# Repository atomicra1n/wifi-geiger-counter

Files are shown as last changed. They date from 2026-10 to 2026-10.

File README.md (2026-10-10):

# Wi-Fi Geiger Counter

a DIY Geiger counter PCB which can detect ionizing radiation and log readings over Wi-Fi,. Built with an ESP32, and a HV multiplier circuit that steps up 3.7V to 400V for the GM tube.



## Features

- M4011/SBM-20 Geiger tube with pulse detection
- Custom HV circuit (around 400V) with a single LiPo cell
- Wi-Fi data logging
- USB-C charging
- ESD and overvoltage protection

Build for [Hack Club Half Life](https://halflife.hackclub.com/) 
Week 1 (PCBs).

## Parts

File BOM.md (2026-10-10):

# Wi-Fi Geiger Counter – bill of materials

<!-- Generated by Half Life from project cmuvjsap500od01pymkzg6tec. Edits here are overwritten on the next sync. -->
<!-- Generated: 2026-10-10T20:25:37.913Z -->

> [!NOTE]
> This parts list is mirrored from [Half Life](https://halflife.hackclub.com). Editing it here will not change the platform's copy, and the next sync overwrites this file.

| Week | Tier | Parts funding |
| --- | --- | --- |
| Week 1 | Tier 2 | $65.00 |

| Part | What it's for | Qty | Unit | Total | Vendor |
| --- | --- | --- | --- | --- | --- |
| [PCB Manufacturing](https://jlcpcb.com) | The entire PCB itself | 1 | $4.00 | $4.00 | [JLCPCB](https://jlcpcb.com) |
| [EPS32-C3-MINI](https://www.lcsc.com/product-detail/C2838502.html) | The PCB controller | 1 | $3.06 | $3.06 | [LCSC](https://www.lcsc.com/product-detail/C2838502.html) |
| [TP4056-42-ESOP8](https://www.lcsc.com/product-detail/C16581.html) | Charges the LiPo battery from USB | 5 | $0.19 | $0.95 | [LCSC](https://www.lcsc.com/product-detail/C16581.html) |
| [AP2112K-3.3TRG1](https://www.lcsc.com/product-detail/C51118.html) | Regulates battery voltage down to 3.3V | 5 | $0.18 | $0.90 | [LCSC](https://www.lcsc.com/product-detail/C51118.html) |
| [USBLC6-2SC6](https://www.lcsc.com/product-detail/C7519.html) | Protects USB data lines from static | 5 | $0.18 | $0.90 | [LCSC](https://www.lcsc.com/product-detail/C7519.html) |
| [MMBTA42](https://www.lcsc.com/product-detail/C94389.html) | Switches the inductor for HV boost converter | 10 | $0.05 | $0.50 | [LCSC](https://www.lcsc.com/product-detail/C94389.html) |
| [MMBT3904](https://www.lcsc.com/product-detail/C242260.html) | Pulse detection + buzzer driver | 20 | $0.04 | $0.80 | [LCSC](https://www.lcsc.com/product-detail/C242260.html) |
| [US1M](https://www.lcsc.com/product-detail/C81191.html) | HV multiplier rectifier diodes | 3 | $0.05 | $0.15 | [LCSC](https://www.lcsc.com/product-detail/C81191.html) |
| [1N4148W](https://www.lcsc.com/product-detail/C917030.html) | Buzzer flyback diode | 50 | $0.01 | $0.50 | [LCSC](https://www.lcsc.com/product-detail/C917030.html) |
| [SMF5.0A](https://www.lcsc.com/product-detail/C151296.html) | USB TVS protection | 5 | $0.13 | $0.65 | [LCSC](https://www.lcsc.com/product-detail/C151296.html) |
| [MM3Z3V3](https://www.lcsc.com/product-detail/C52056.html) | 3.3V zener clamp on pulse input | 50 | $0.02 | $1.00 | [LCSC](https://www.lcsc.com/product-detail/C52056.html) |
| [Red LED 0805](https://www.lcsc.com/product-detail/C84256.html) | Charge + status indicators | 50 | $0.02 | $1.00 | [LCSC](https://www.lcsc.com/product-detail/C84256.html) |
| [Yellow LED 0805](https://www.lcsc.com/product-detail/C84261.html) | Charge complete indicator | 20 | $0.02 | $0.40 | [LCSC](https://www.lcsc.com/product-detail/C84261.html) |
| [MLT-8530](https://www.lcsc.com/product-detail/C94599.html) | Click and alarm buzzer | 5 | $0.21 | $1.05 | [LCSC](https://www.lcsc.com/product-detail/C94599.html) |
| [FNR6045S103KT](https://www.lcsc.com/product-detail/C168108.html) | HV boost inductor | 5 | $0.25 | $1.25 | [LCSC](https://www.lcsc.com/product-detail/C168108.html) |
| [TYPE-C-31-M-12](https://www.lcsc.com/product-detail/C165948.html) | USB-C charging port | 5 | $0.18 | $0.90 | [LCSC](https://www.lcsc.com/product-detail/C165948.html) |
| [S2B-PH-K-S-GW](https://www.lcsc.com/product-detail/C157932.html) | Battery connector | 5 | $0.17 | $0.85 | [LCSC](https://www.lcsc.com/product-detail/C157932.html) |
| [1k 0805](https://www.lcsc.com/product-detail/C17513.html) | LED/transistor current limiting, pulse protection | 100 | $0.01 | $1.00 | [LCSC](https://www.lcsc.com/product-detail/C17513.html) |
| [10k 0805](https://www.lcsc.com/product-detail/C17414.html) | Pullups, pulldowns, base resistors | 100 | $0.01 | $1.00 | [LCSC](https://www.lcsc.com/product-detail/C17414.html) |
| [5.1k 0805](https://www.lcsc.com/product-detail/C27834.html) | USB-C CC pulldowns | 100 | $0.01 | $1.00 | [LCSC](https://www.lcsc.com/product-detail/C27834.html) |
| [2.2k 0805](https://www.lcsc.com/product-detail/C17520.html) | TP4056 charge current setting | 100 | $0.01 | $1.00 | [LCSC](https://www.lcsc.com/product-detail/C17520.html) |
| [220k 0805](https://www.lcsc.com/product-detail/C17556.html) | HV feedback divider bottom | 100 | $0.01 | $1.00 | [LCSC](https://www.lcsc.com/product-detail/C17556.html) |
| [100k 0805](https://www.lcsc.com/product-detail/C17407.html) | Tube cathode load resistor | 100 | $0.01 | $1.00 | [LCSC](https://www.lcsc.com/product-detail/C17407.html) |
| [4.7M 1206 500V](https://www.lcsc.com/product-detail/C510138.html) | Tube anode current limiter | 10 | $0.01 | $0.10 | [LCSC](https://www.lcsc.com/product-detail/C510138.html) |
| [10M 1206](https://www.lcsc.com/product-detail/C2933576.html) | HV feedback divider chain | 100 | $0.01 | $1.00 | [LCSC](https://www.lcsc.com/product-detail/C2933576.html) |
| [10µF 0805](https://www.lcsc.com/product-detail/C15850.html) | Power rail decoupling | 20 | $0.07 | $1.40 | [LCSC](https://www.lcsc.com/product-detail/C15850.html) |
| [1µF 0805](https://www.lcsc.com/product-detail/C28323.html) | LDO input/output filtering | 10 | $0.04 | $0.40 | [LCSC](https://www.lcsc.com/product-detail/C28323.html) |
| [100nF 0805](https://www.lcsc.com/product-detail/C49678.html) | High-frequency decoupling | 20 | $0.02 | $0.40 | [LCSC](https://www.lcsc.com/product-detail/C49678.html) |
| [10nF 1kV 1206](https://www.lcsc.com/product-detail/C107192.html) | HV multiplier stage caps | 20 | $0.03 | $0.60 | [LCSC](https://www.lcsc.com/product-detail/C107192.html) |
| [Tact switch](https://www.lcsc.com/product-detail/C318884.html) | Reset + boot buttons | 20 | $0.02 | $0.40 | [LCSC](https://www.lcsc.com/product-detail/C318884.html) |
| [GM Tube - M4011](https://github.com/SensorsIot/Geiger-Counter-RadiationD-v1.1-CAJOE-/blob/master/M4011%20Geiger%20Tube%20Specification.pdf) | Detecting radioactive impulses | 1 | $0.01 | $0.01 | [Myself - Salvaged from FNIRSI GC-01](https://github.com/SensorsIot/Geiger-Counter-RadiationD-v1.1-CAJOE-/blob/master/M4011%20Geiger%20Tube%20Specification.pdf) |
| [3.7V LiPo battery](https://tipa.eu/en-en/products/rechargeable-battery-lipo-3-7v4200mah-105565-hadex) | Power delivery | 1 | $0.01 | $0.01 | [Myself - Salvaged from FNIRSI GC-01](https://tipa.eu/en-en/products/rechargeable-battery-lipo-3-7v4200mah-105565-hadex) |
| [2.54-1*3P](https://www.lcsc.com/product-detail/C49257.html) | GM Tube pin header | 20 | $0.03 | $0.60 | [LCSC](https://www.lcsc.com/product-detail/C49257.html) |
| **Parts subtotal** | — | — | — | **$29.78** | — |
| **Tax & shipping** | — | — | — | **$25.00** | — |
| **Total** | — | — | — | **$54.78** | — |

$10.22 left of the tier's funding.

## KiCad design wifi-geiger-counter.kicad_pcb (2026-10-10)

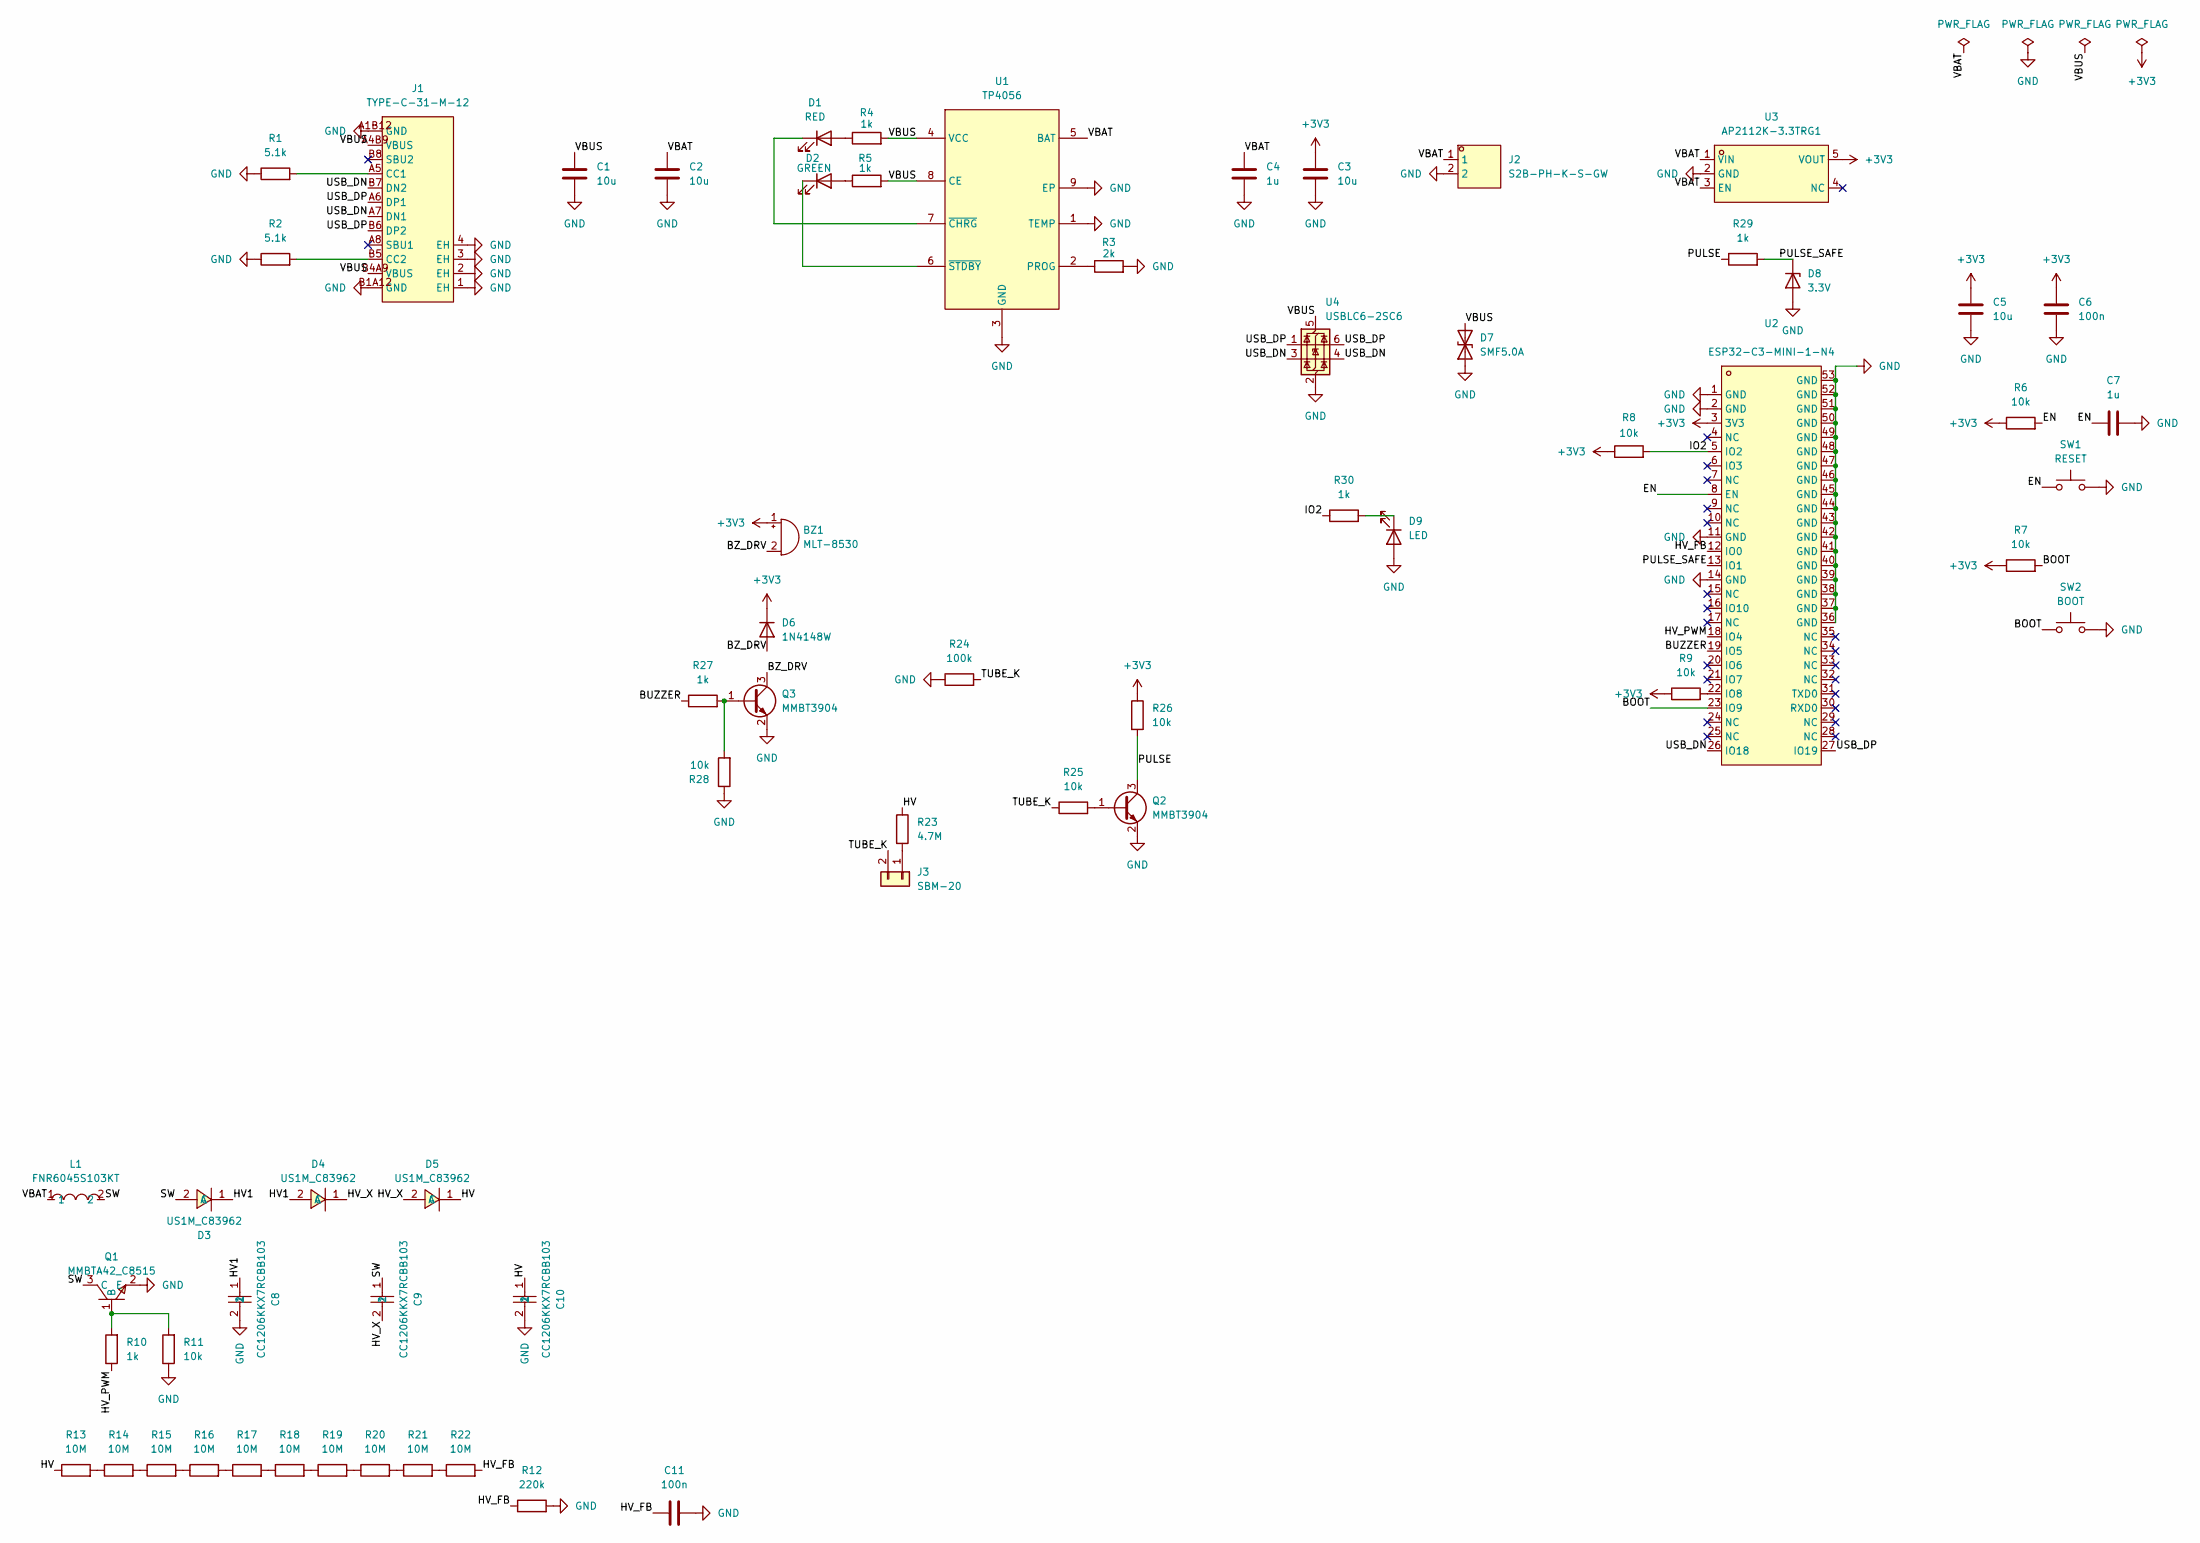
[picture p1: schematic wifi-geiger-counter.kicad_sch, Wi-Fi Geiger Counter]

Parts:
BZ1: MLT-8530; Buzzer_Murata_PKMCS0909E
C1, C2, C3, C5: 10u; C_0805_2012Metric
C4, C7: 1u; C_0805_2012Metric
C6, C11: 100n; C_0805_2012Metric
C8, C9, C10: CC1206KKX7RCBB103; C1206; MPN CC1206KKX7RCBB103; LCSC Part C107192
D1: RED; LED_0805_2012Metric
D2: GREEN; LED_0805_2012Metric
D3, D4, D5: US1M_C83962; SMA_L4.3-W2.6-LS5.2-RD; MPN US1M; LCSC Part C83962
D6: 1N4148W; D_SOD-123
D7: SMF5.0A; D_SOD-123F
D8: 3.3V; D_SOD-323
D9: LED; LED_0805_2012Metric
J1: TYPE-C-31-M-12; USB-C_SMD-TYPE-C-31-M-12_1; MPN TYPE-C-31-M-12; LCSC Part C165948
J2: S2B-PH-K-S-GW; CONN-TH_S2B-PH-K-S-GW; MPN S2B-PH-K-S-GW; LCSC Part C157932
J3: SBM-20; PinHeader_1x02_P2.54mm_Vertical
L1: FNR6045S103KT; IND-SMD_L6.0-W6.0_FNR60XXS; MPN FNR6045S103KT; LCSC Part C168108
Q1: MMBTA42_C8515; SOT-23-3_L2.9-W1.3-P1.90-LS2.4-BR; MPN MMBTA42(RANGE:100-200); LCSC Part C8515
Q2, Q3: MMBT3904; SOT-23
R1, R2: 5.1k; R_0805_2012Metric
R3: 2k; R_0805_2012Metric
R4, R5, R10, R27, R29, R30: 1k; R_0805_2012Metric
R6, R7, R8, R9, R11, R25, R26, R28: 10k; R_0805_2012Metric
R12: 220k; R_0805_2012Metric
R13, R14, R15, R16, R17, R18, R19, R20, R21, R22: 10M; R_1206_3216Metric
R23: 4.7M; R_1206_3216Metric
R24: 100k; R_0805_2012Metric
SW1: RESET; SW_SPST_CK_KMS2xxGP
SW2: BOOT; SW_SPST_CK_KMS2xxGP
U1: TP4056; ESOP-8_L4.9-W3.9-P1.27-LS6.0-BL-EP; MPN TP4056-42-ESOP8; LCSC Part C16581
U2: ESP32-C3-MINI-1-N4; WIFIM-SMD_ESP32-C3-MINI-1; MPN ESP32-C3-MINI-1-N4; LCSC Part C2838502
U3: AP2112K-3.3TRG1; SOT-25-5_L2.9-W1.6-P0.95-LS2.8-BL; MPN AP2112K-3.3TRG1; LCSC Part C51118
U4: USBLC6-2SC6; SOT-23-6

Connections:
+3V3: BZ1.1 (+), C3.1, C5.1, C6.1, D6.1 (K), R6.1, R7.1, R8.1, R9.1, R26.1, U2.3 (3V3), U3.5 (VOUT)
/BOOT: R7.2, SW2.1, U2.23 (IO9)
/BUZZER: R27.1, U2.19 (IO5)
/BZ_DRV: BZ1.2 (-), D6.2 (A), Q3.3 (C)
/EN: C7.2, R6.2, SW1.1, U2.8 (EN)
/HV: C10.1, D5.1 (C), R13.1, R23.1
/HV1: C8.1, D3.1 (C), D4.2 (A)
/HV_FB: C11.1, R12.1, R22.2, U2.12 (IO0)
/HV_PWM: R10.1, U2.18 (IO4)
/HV_X: C9.2, D4.1 (C), D5.2 (A)
/IO2: R8.2, R30.1, U2.5 (IO2)
/PULSE: Q2.3 (C), R26.2, R29.1
/PULSE_SAFE: D8.1 (K), R29.2, U2.13 (IO1)
/SW: C9.1, D3.2 (A), L1.2, Q1.3 (C)
/TUBE_K: J3.2, R24.2, R25.1
/USB_DN: J1.A7 (DN1), J1.B7 (DN2), U2.26 (IO18), U4.3 (I/O2), U4.4 (I/O2)
/USB_DP: J1.A6 (DP1), J1.B6 (DP2), U2.27 (IO19), U4.1 (I/O1), U4.6 (I/O1)
/VBAT: C2.1, C4.1, J2.1, L1.1, U1.5 (BAT), U3.1 (VIN), U3.3 (EN)
/VBUS: C1.2, D7.2 (A2), J1.A4B9 (VBUS), J1.B4A9 (VBUS), R4.2, R5.2, U1.4 (VCC), U1.8 (CE), U4.5 (VBUS)
GND: C1.1, C2.2, C3.2, C4.2, C5.2, C6.2, C7.1, C8.2, C10.2, C11.2, D7.1 (A1), D8.2 (A), D9.2 (A), J1.1 (EH), J1.2 (EH), J1.3 (EH), J1.4 (EH), J1.A1B12 (GND), J1.B1A12 (GND), J2.2, Q1.2 (E), Q2.2 (E), Q3.2 (E), R1.1, R2.1, R3.2, R11.1, R12.2, R24.1, R28.1, SW1.2, SW2.2, U1.1 (TEMP), U1.3 (GND), U1.9 (EP), U2.1 (GND), U2.2 (GND), U2.11 (GND), U2.14 (GND), U2.36 (GND), U2.37 (GND), U2.38 (GND), U2.39 (GND), U2.40 (GND), U2.41 (GND), U2.42 (GND), U2.43 (GND), U2.44 (GND), U2.45 (GND), U2.46 (GND), U2.47 (GND), U2.48 (GND), U2.49 (GND), U2.50 (GND), U2.51 (GND), U2.52 (GND), U2.53 (GND), U3.2 (GND), U4.2 (GND)
unnamed: D1.2 (A), R4.1
unnamed: D1.1 (K), U1.7 (~CHRG)
unnamed: D2.2 (A), R5.1
unnamed: D2.1 (K), U1.6 (~STDBY)
unnamed: D9.1 (K), R30.2
unnamed: J1.A5 (CC1), R1.2
unnamed: J1.B5 (CC2), R2.2
unnamed: J3.1, R23.2
unnamed: Q1.1 (B), R10.2, R11.2
unnamed: Q2.1 (B), R25.2
unnamed: Q3.1 (B), R27.2, R28.2
unnamed: R13.2, R14.1
unnamed: R14.2, R15.1
unnamed: R15.2, R16.1
unnamed: R16.2, R17.1
unnamed: R17.2, R18.1
unnamed: R18.2, R19.1
unnamed: R19.2, R20.1
unnamed: R20.2, R21.1
unnamed: R21.2, R22.1
unnamed: R3.1, U1.2 (PROG)
unnamed: R9.2, U2.22 (IO8)

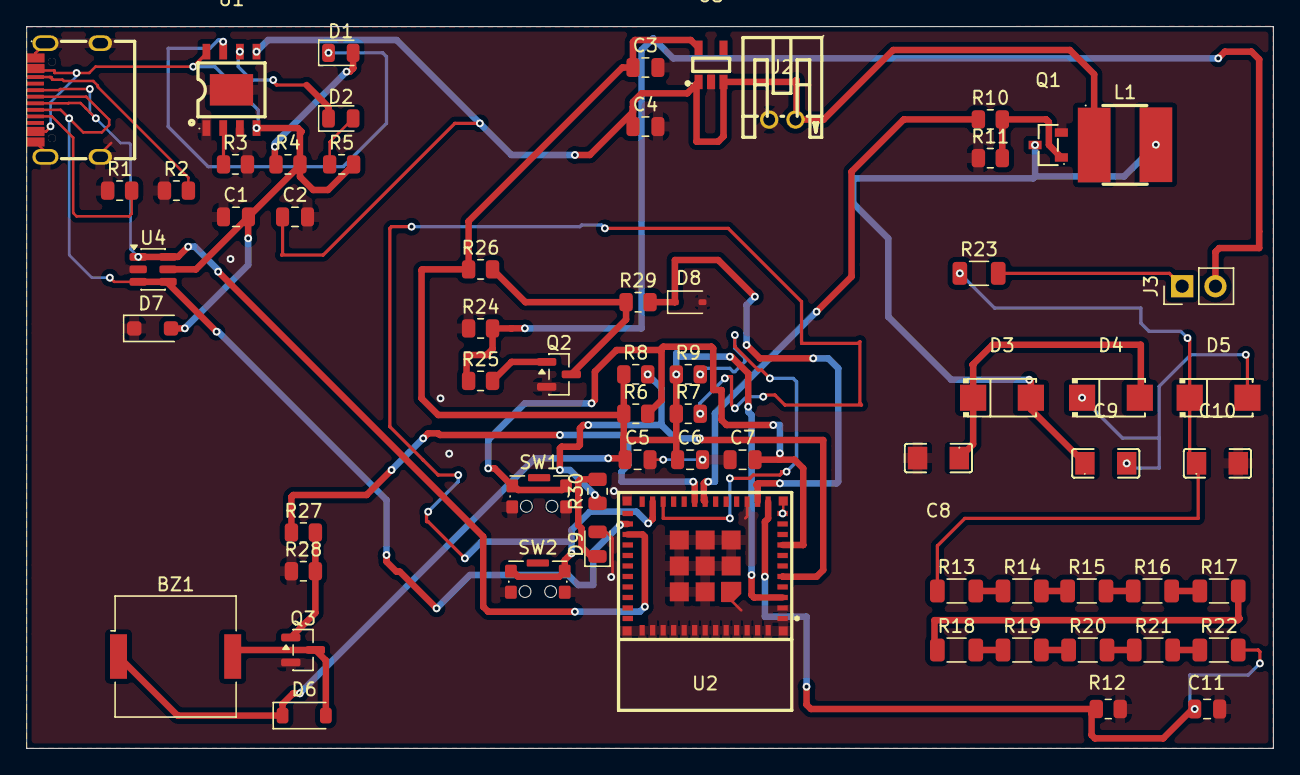
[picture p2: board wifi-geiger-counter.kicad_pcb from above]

Board: 2 copper layers, 95.0 x 55.0 mm, 64 parts (0 on the bottom side), 42 nets.

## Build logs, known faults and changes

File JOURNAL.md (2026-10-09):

# Wi-Fi Geiger Counter – devlog

<!-- Generated by Half Life from project cmuvjsap500od01pymkzg6tec. Edits here are overwritten on the next sync. -->
<!-- Generated: 2026-10-08T21:40:39.430Z -->

> [!NOTE]
> This devlog is mirrored from [Half Life](https://halflife.hackclub.com). Editing it here will not change the platform's copy, and the next sync overwrites this file.

> A Geiger counter that logs current radiation levels over Wi-Fi. Uses a SBM-20 Geiger tube, ESP32-C3 and a self-designed high voltage supply. Powered over USB-C + a battery.

| Week | Tier | Hours logged | Entries |
| --- | --- | --- | --- |
| Week 1 | Tier 2 | 17h | 4 |

## Contents

1. [2026-10-06 – # Oct 5: Planning and first work in KiCad](#2026-10-06-oct-5-planning-and-first-work-in-kicad)
2. [2026-10-06 – # Oct 6: Footprint assignment](#2026-10-06-oct-6-footprint-assignment)
3. [2026-10-07 – # Oct 7: PCB layout: placement and first routing](#2026-10-07-oct-7-pcb-layout-placement-and-first-routing)
4. [2026-10-08 – # Oct 8: Routing the board](#2026-10-08-oct-8-routing-the-board)

## Design

### 2026-10-06 – # Oct 5: Planning and first work in KiCad

**9h**

# Oct 5: Planning and first work in KiCad
After coming up with my project concept, I first decided to make a list of the parts I would work with and features I would want. I already have a FNIRSI GC-01 Geiger Counter, so I have a good reference of readings and problems with it. The readings often jump a lot at low radiation levels (background) and there is no Wi-Fi functionality. So I've decided my Geiger will support Wi-Fi ([ESP32-C3](https://documentation.espressif.com/esp32-c3_datasheet_en.pdf))  and use a SBM-20 tube (quite a bit bigger than the M4011 in the FNIRSI and should be more reliable). On top of the ESP and the tube, I will need a high voltage supply which I will design and some other smaller electronics (like a buzzer for impulses and a USB-C port for charging).

The SBM-20 tube needs about 400 volts to operate (see [datasheet](https://www.gstube.com/data/2398/)), which is quite scary, considering we are starting with 3.3 Volts. I researched some ways to get there, and although I was considering making a simple straight boost converter (single inductor all the way to 400V), I decided to go with something called a [Cockcroft-Walton voltage multiplier](https://en.wikipedia.org/wiki/Cockcroft%E2%80%93Walton_generator). It's a bit more efficient on the components, as the inductor only needs around 130 Volts (we can use cheaper caps rated for lower voltage) and the chain of diodes and capacitators will triple it, reaching our desired 400 volts.

After getting a rough idea of the whole project structure, I decided to install KiCad. I didn't have much experience, so I spent the first few minutes just looking around and figuring out the basics controls. After making the project, I was able to find the specific components I would use on [lscs](https://www.lcsc.com/) and imported them into KiCad (notably the USB-C port, ESP32 and so on).

Here's my finished LCSC cart (after the schematic was done):
Finished LCSC cart

After looking around, I was still a bit worried about the High Voltage part of the project, so I decided to sketch out the Cockcroft-Walton multiplier on paper. I was a bit confused about the orientation of some components, but later figured it out after a few attempts.

My attempt at a Cockcroft-Walton multiplier

Next, it was time to actually lay stuff down in KiCad. So I started with the power section, as our Geiger wil certainly not work without power. After doing a bit of research into USB-C connectors, I realized the USB-C connector needs 5.1 kiloohm pulldown resistors on the CC pins, so I made a simple charging circuit in KiCad:

USB-C and TP4056 charging circuit

**Next up:** The hardest part of the project, high voltage circuit.

**tl;dr: Picked out components, setup and learned KiCAD basics, drafted high voltage circuit, made basic charging circuit**

**In total, the time spent doing research, assembling part lists, drawing the circuits and creating the charging circuit was 3 hours.**

# Oct 6: High voltage supply
This was definitely the hardest part of the entire schematic. I picked the MMBTA42 transistor, which switches the inductor via PWM from the ESP32. When it switches off, the energy of the inductor goes through the first diode and the multiplier chain steps it up step by step.

Multiplier chain of the HV circuit

A problem I didn't expect was the feedback divider. I need to bring down 400V down to something the ESP32 can handle. I thought of using a simple voltage divider, but the top resistor would need to be around 100 megaohms, and I quickly figured out that a simple 0805 resistor is rated only for 150 volts. So I decided to put 10 10megaohm resistors in a series to spread the voltage. The bottom one is 220k, which gives a ratio of about 455:1, leading to only 0.88V on the ESP32's ADC.

Feedback divider

When the board is off, the divider also slowly drains the HV capacitors through 100 megaohms, so that the user doesn't get shocked handling the board afterwards.

Finished HV circuit

**Next up:** Wiring the ESP32 and detecting radioactive impulses.

**tl;dr: Built the high voltage circuit stepping up to 400 volts.**

**Total time spent: ~2.5 hours**

# Oct 6: ESP32 wiring and pulse detection
It was a bit tricky getting the pin assignment on the ESP32 right. I needed to check the datasheet to figure out which support ADC and which do PWM.
ESP32 wiring

The SBM-20 tube connects through a 2-pin header. The anode of the tube gets around 400V through a 4.7megaohm resistor, which limits the current to about 85 microampers. When a radioactive decay event is detected, a particle ionizes the gas inside the SBM-20 tube and the tube conducts briefly, causing the cathode to drop. An MMBT3904 transistor is used to invert that into a clean signal for the ESP32.

The buzzer uses another MMBT3904 transistor as a switch. I had to add a 10kiloohm pulldown resistor on the base because the pins of the ESP32 can float during boot and the buzzer could make random noises as it boots. I also added a flyback diode across the buzzer, so when the transistor switches off it kicks back a voltage spike, and the diode gives it somewhere to go.
Buzzer and pulse detection area

**Next up:** Final checks and safety

**tl;dr: Setup the wiring for the SBM-20 Geiger tube and added pulse detection, added the buzzer for detecting impulses**

**Total time spent: ~2 hours**

# Oct 6: Protection circuits and final checks
To finish the schematic, I added ESD protection (USBLC6-2) on the USB data lines to make sure that static from plugging a cable cannot kill the ESP32. Another diode on the VBUS handles voltage spikes from bad chargers.
Protection circuits

To finalize my schematic, I ran the Electrical Rules Checker in KiCad, which came back without errors.

Passing ERC

Final schematic:

Final schematic

**Next up:** Footprint assignment and starting the PCB layout

**tl;dr: Added ESD and overvoltage protection, schematic passes ERC. Schematic is done.**

**Total time spent: ~1.5 hours**

### 2026-10-06 – # Oct 6: Footprint assignment

**1.5h**

# Oct 6: Footprint assignment

After my schematic was finished, I decided to begin the necessary work before I could actually start designing the PCB itself. The first step was assigning physical footprints to each component in my schematic, as KiCAD needs to know how big each resistor, capacitor and all the other components are.

Given that many of my components were imported from LCSC, they already had a lot of footprints, but most of the passive components (resistors, capacitors and diodes) needed me to manually assign them.

For the resistors, I picked the 0805 resistor as it is small enough, but can still be soldered by hand. Parts of the HV circuit needed different resistors though, notably the feedback divider, as 0805 is only rated for 150 Volts. I picked the 1206, as it is rated higher and is a similar size to the 0805.
Assigned footprints

Diodes were a bit more confusing, but I ended up choosing SOD-123, SOD-123F and SOD-323. The buzzer was the biggest problem, as my model wasn't in the library. Ended up choosing the closest one, which was a Murata 9x9 buzzer, should be relatively close to the real one.

After assigning all footprints, I opened the PCB Editor for the first time, where I was quickly greeted with a huge mess. But that's a problem for tomorrow!

Tomorrow's problems

**Next up:** PCB outline and component placement

**tl;dr: Added footprints to all components, imported my schematic in the PCB editor.**

**Total time spent: ~1.5 hours**

### 2026-10-07 – # Oct 7: PCB layout: placement and first routing

**3h**

# Oct 7: PCB layout: placement and first routing

Today, I started the actual layout of the PCB. First, I setup the board outline to be 90x50mm and started placed components. On the left, I put USB-C and charging related components. On the top right, I put the battery and LDO. I decided to put the ESP32 in the center of the board with its antenna pointing down, and I isolated the entire High Voltage circuit on the right with a bigger gap from everything else.

The board with all components placed

The SBM-20 tube will mount externally through our 2-pin header. Given the tube is 108mm long, it cannot fit on the board. This may be an advantage though, as you can point it at any surface or material freely.

Afterwards, I decided to configure design rules for safety. I made a special net class for the high voltage circuit with 6mm clearance to make sure that traces do not arc across the board at 400V.

Configured net classes

To finish the work for the day, I started work on the routing. I mostly familiarized myself with how it works, and tried routing the basics of the HV circuit, but it is only a rough sketch for now and will need a lot more work.

Absolute basics of routing in the HV circuit

**Next up:** Finishing routing the board.

**tl;dr: Components placed on the actual PCB, design rules set, began work on learning how to route.**

**Total time spent: ~3 hours**

### 2026-10-08 – # Oct 8: Routing the board

**3.5h**

# Oct 8: Routing the board

I started properly working on the routing today. At the start, it was really rough. Yesterday, I started with the HV section. However, I quickly realized this is super challenging. I had no idea how to arrange the routes for it all to fit. I would just choose a pad, press X and start routing, but quickly ran out of space and paths for the traces to go.

Traces from yesterday in the HV section

I decided it would be a good idea to take a breather and try working on an easier section than HV. So I decided the USB-C section could be a good idea. I immediately ran into issues though. The pin spacing on the connector was so tight that my traces violated the spacing rules. I could not connect any pins of the port itself. At the very least, I tried routing the nearby components, which proved to be less of a challenge.

USB-C section

After wiring a few things here, I decided to move to the middle, more notably the pins of the ESP32 and surrounding components (e.g. buzzer circuit). However, I quickly got a lot more frustrated when I realized there was no way I was gonna fit the traces. What was I meant to do? Rearrange everything? I was desperate and almost resorted to cheating, as I thought this must be a problem someone solved and looked for software that could auto route circuits. However, I felt it was unfair and after all, I was here to learn, so I tried looking for ways to properly route it. With just 5 minutes of exploring the editor, I made a massive revelation. **There are two layers!** Turns out, sometimes it's a good idea to approach problems with some problem-solving skill instead of slaving away at impossible tracing. I ended up fixing a few of my poor traces from when I assumed there was only one layer, and I started with routing the rest of the board, this time much more quicker.

I wired up the ESP32 layer, but later realized I made a mistake at the bottom, when I ran a trace through the bottom of it, where the antenna supposedly sits. This could cause major issues for the ESP32, and so I had to redo that trace, which was thankfully very simple with layer switching.

ESP32 antenna wiring mistake

Now, I'll be honest. My tracing is nowhere near exemplary, but I still am very proud of the fact that it is getting to a functional state.

Today's routing progress

Near the end, I realized another fatal mistake I made near the start. Given that we are working with 400V in the HV section, it is possible for a spark to arc through the board between individual traces (my classmate warned me of that, thanks!). As such, we need to follow clearance rules (I set a 6mm rule to have some headroom). Tomorrow, I will try to have another crack at finishing the USB-C section (I still haven't figured out how to properly connect the pins), fix the HV clearance and overall get routing finished.

**Next up:** Fixing the clearance violations, finishing remaining traces

**tl;dr: Discovered that the PCB has multiple layers, which was a game changer. Most of the board is now routed but a couple traces need rerouting as they carry high voltage and are too close.**

**Total time spent: ~3.5 hours**

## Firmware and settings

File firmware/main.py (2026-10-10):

from machine import Pin, Timer
import time
import config
import geiger
import hv_control
import buzzer
import wifi_manager

print("starting up...")

led = Pin(config.LED_PIN, Pin.OUT)
led.on()

# setup buzzer
buzzer.setup(config.BUZZER_PIN)
buzzer.beep(2700, 100)

# setup geiger counter
geiger.setup(config.PULSE_PIN)
geiger.set_click_callback(buzzer.click)

# setup hv
hv_control.setup(config.HV_PWM_PIN, config.HV_FB_PIN)
hv_control.start()

# run pid at 100hz
tim = Timer(0)
tim.init(freq=100, mode=Timer.PERIODIC, callback=hv_control.update)

# wifi
if wifi_manager.connect(config.WIFI_SSID, config.WIFI_PASS):
    led.off()
    wifi_manager.start(geiger, hv_control)
    print("ready")
else:
    print("no wifi, running offline")

while True:
    wifi_manager.check()
    
    # debug
    cpm = geiger.get_cpm()
    usvh = geiger.get_usvh()
    hv = hv_control.get_voltage()
    print("cpm:", round(cpm), ", usvh:", round(usvh, 4), ", hv:", round(hv), "V")
    
    time.sleep(5)

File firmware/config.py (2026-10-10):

# pin assignments
HV_PWM_PIN = 4
HV_FB_PIN = 0 
PULSE_PIN = 1
BUZZER_PIN = 5
LED_PIN = 2

# the feedback divider is 100M/220k so ratio is like 454.5
# 400v / 454.5 = 0.88v = 880mv on the adc
HV_TARGET = 880

# m4011 tube conversion factor
CPM_TO_USVH = 0.0057

WIFI_SSID = ""
WIFI_PASS = ""

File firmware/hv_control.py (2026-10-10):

from machine import Pin, PWM, ADC

pwm = None
adc = None
duty = 0
running = False

# pid
kp = 0.5
ki = 0.1
kd = 0.05
integral = 0
last_err = 0

def setup(pwm_pin, fb_pin):
    global pwm, adc
    pwm = PWM(Pin(pwm_pin), freq=20000, duty=0)
    adc = ADC(Pin(fb_pin))
    adc.atten(ADC.ATTN_11DB)

def read_mv():
    raw = adc.read()
    return int(raw / 4095 * 3300)

def get_voltage():
    # multiply by divider ratio to get actual hv
    return read_mv() * 455 / 1000

def update(timer=None):
    global duty, integral, last_err
    if not running:
        return
    
    from config import HV_TARGET
    
    mv = read_mv()
    err = HV_TARGET - mv
    
    integral += err
    # clamp
    if integral > 1000:
        integral = 1000
    if integral < -1000:
        integral = -1000
    
    d = err - last_err
    last_err = err
    
    out = kp * err + ki * integral + kd * d
    duty = int(duty + out)
    
    if duty < 0:
        duty = 0
    if duty > 1023:
        duty = 1023
    
    pwm.duty(duty)

def start():
    global running, integral, duty
    running = True
    integral = 0
    duty = 0

def stop():
    global running, duty
    running = False
    duty = 0
    pwm.duty(0)

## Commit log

2026-10-05 Power section: USB-C, TP4056 charger, LDO
    [wifi-geiger-counter.kicad_pcb, wifi-geiger-counter.kicad_sch]
2026-10-06 400V circuit
    [wifi-geiger-counter.kicad_sch]
2026-10-06 add protections, schematic clean
    [wifi-geiger-counter.kicad_sch]
2026-10-06 assign footprints, import into pcb editor
    [wifi-geiger-counter.kicad_pcb, wifi-geiger-counter.kicad_sch]
2026-10-07 PCB layout, placement, first routing, design rules
    [wifi-geiger-counter.kicad_pcb]
2026-10-08 Most routing done
    [wifi-geiger-counter.kicad_pcb]
2026-10-09 routing probably done, pre ground pour
    [wifi-geiger-counter.kicad_pcb]
2026-10-09 finish pour and clear warnings and errors, cleanup, routing done.
    [wifi-geiger-counter.kicad_pcb]
2026-10-10 Finish all PCB work
    [wifi-geiger-counter-B_Cu.gbr, wifi-geiger-counter-B_Mask.gbr, wifi-geiger-counter-B_Silkscreen.gbr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]
2026-10-11 gnd pour esp antenna rule zone
2026-10-11 reexport gerbers
2026-10-16 Fix PCB issues, address design feedback
    Fixing the BOM.csv, README, folder structuring and design flaws
    - Moved KiCad things, libraries, gerbers, etc. into pcb/
    - Added BOM.csv and improved README
    - Fixed TVS polarity, status LED, buzzer footprint
    - Fixed USB-C connector orientation
    - Fixed net class patterns and clearance
    - ADC/PWM/conversion factor firmware fixes
